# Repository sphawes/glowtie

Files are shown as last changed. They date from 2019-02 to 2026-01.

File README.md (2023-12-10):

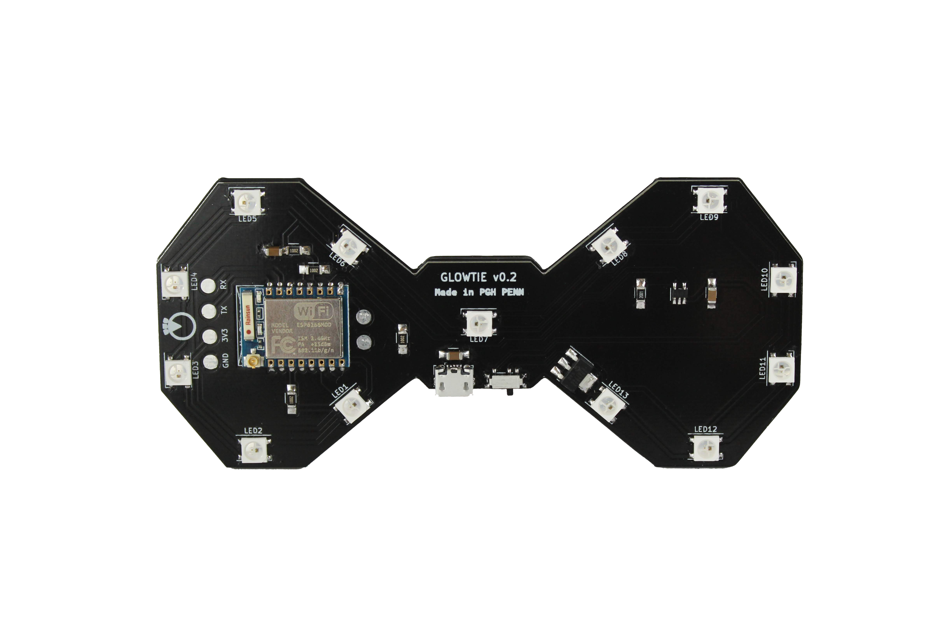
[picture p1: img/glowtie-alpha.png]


## Connecting to your Glowtie

### Android

1. Turn on your Glowtie. There’s a power switch next to the micro usb jack. You should see a gold burst animation; this means the Wifi network has started.
1. On your Android phone, turn off your mobile data. This is so that your phone doesn’t try to reach the actual internet instead of the Glowtie.
1. Open your Wifi settings and look for a network named in the format “AdjectiveClothing”. For example, it could be “FancyPants” or “CoolCoat”. This is the Serial Name of your Glowtie. Connect to the network.
1. You may get a notification that the network you connected to does not have internet access, no worries! Just choose the option to stay connected if you are provided with one.
1. Now open a new tab in Google Chrome and enter the following in the address field: http://192.168.4.1
1. You should see the Glowtie control page! In your Chrome settings, choose to “Add to Home screen” to make it easier to get to in the future.

### iPhone

1. Turn on your Glowtie. You should see a gold burst animation; this means the Wifi network has started.
1. On your iPhone, navigate to Settings -> Cellular and toggle Cellular Data off. This is so that your phone doesn’t try to reach the actual internet instead of the Glowtie.
1. Open your Wifi settings and look for a network named in the format “AdjectiveClothing”. For example, it could be “FancyPants” or “CoolCoat”. This is the Serial Name of your Glowtie. Connect to the network.
1. You may get a notification that the network you connected to does not have internet access, no worries! Just choose the option to stay connected if you are provided with one.
1. Now open a new tab in Safari or Google Chrome and enter the following in the address field: http://192.168.4.1
1. You should see the Glowtie control page! In your Chrome settings, choose to “Add to Home screen” to make it easier to get to in the future. In Safari, tap the share button and select “Add to Home Screen” to do the same.

## Usage

When you load the Glowtie website, you’ll see three sliders. These represent the red, green, and blue values of the lights. When you adjust them, the title background will adjust to show you what color you’re set to.

Once you pick a color, there’s a few options for animations. Tap the button next to the animation you want, then hit the “UPDATE” button. Your Glowtie will change to whatever you selected!



The Glowtie has a built-in memory function, so once you choose a color and animation it’ll remember your choice after you turn it off. This way, you don’t need to connect to it every time you turn it on if you have it set to your favorite pattern.

## Charging

When the Glowtie has low battery, the center LED will turn red. Use a Micro USB cable to recharge your Glowtie. Make sure your Glowtie is turned off, then plug the Micro USB cable into the port next to the power switch. When you plug the other end into a USB port for power, you should see the **top** light on your Glowtie illuminate. When it’s done charging, the **bottom** light will illuminate.

## Cover

Your Glowtie optionally has a diffusion cover. The cover is held on with a friction fit. Laser cut or print `diffusion.dxf` in a white or clear material, 1/16" thick. Print `bumper.stl` in a color of your choice, and super glue the diffusion inside the bumper. The bumper can now be friction fit onto the Glowtie.

## HACK!

The Glowtie is totally open-source. All PCB design files, firmware, and physical parts are hosted on the Github page. There’s a dedicated programming header on the left side so you can add your own animations, or make it do anything you want! Just solder on a few pins and reprogram the ESP8266 over UART.

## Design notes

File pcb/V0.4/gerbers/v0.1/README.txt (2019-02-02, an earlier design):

First version designed for single side, milled on other mill, never sent out

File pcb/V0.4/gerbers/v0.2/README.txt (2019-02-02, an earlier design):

first version sent out to board shop (elecrow) designed for double side, no charging complete or charging indicator lights

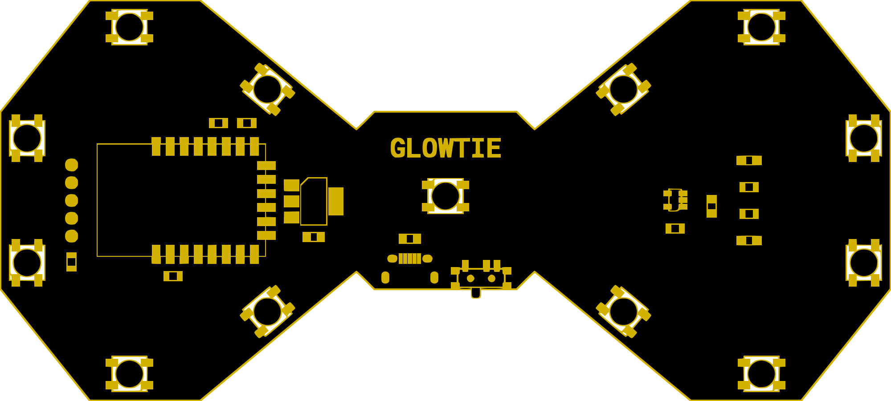
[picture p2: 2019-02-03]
img/glowtieSimplified.png

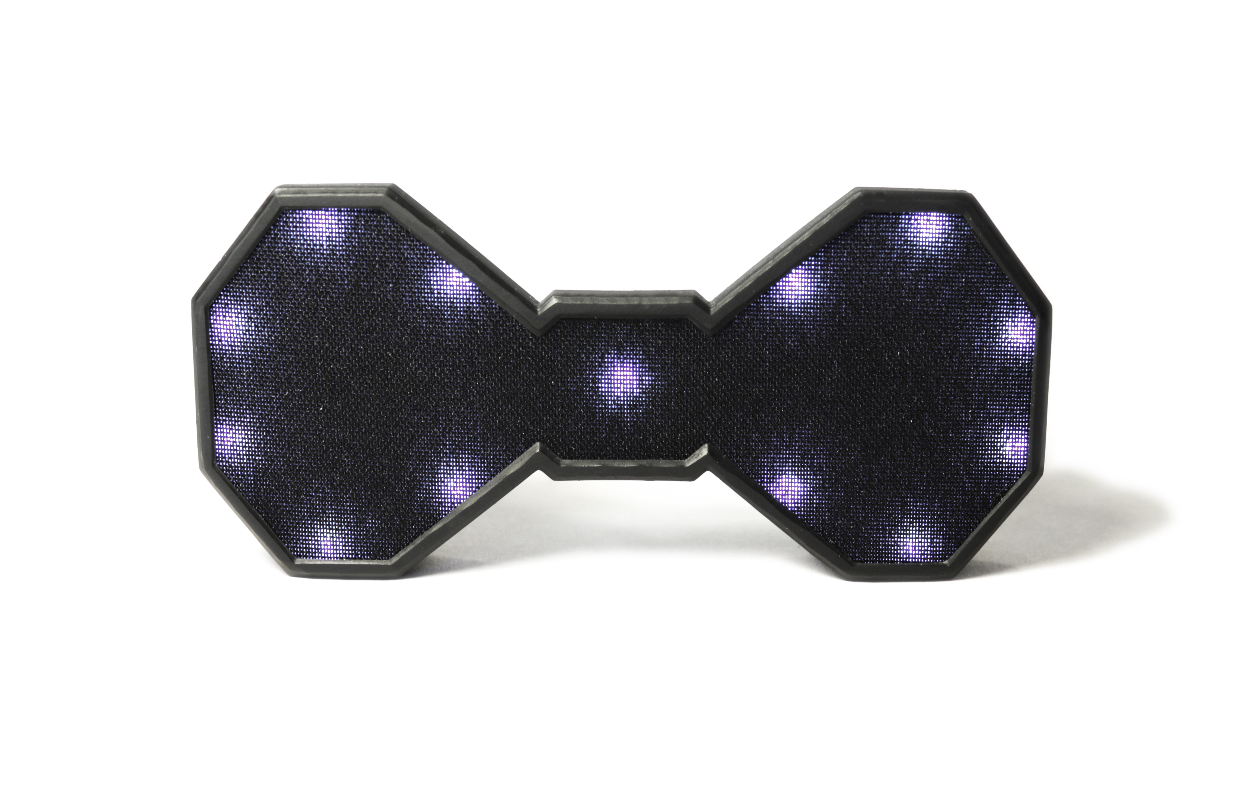
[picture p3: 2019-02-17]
img/glowtieHERO.jpg

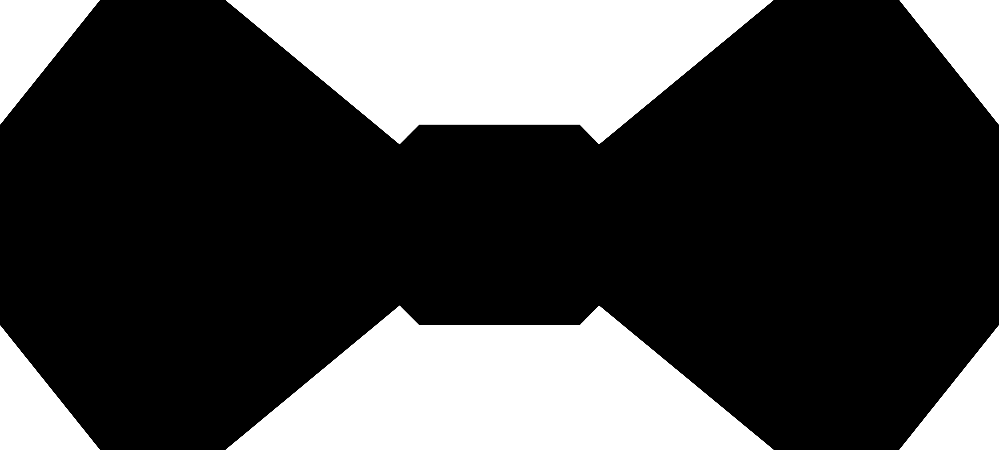
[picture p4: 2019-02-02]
cad/misc/glowtieOutline.jpg

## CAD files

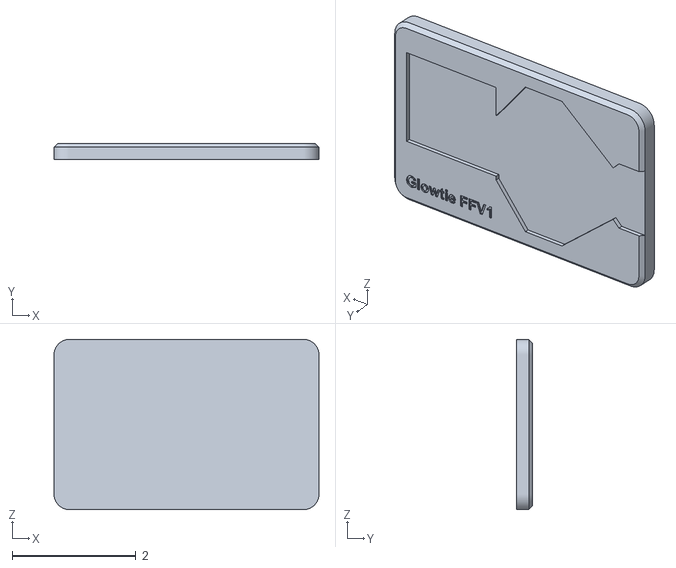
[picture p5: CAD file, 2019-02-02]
cad/misc/firmwareFlasher.stl
4.28 x 0.26 x 2.75

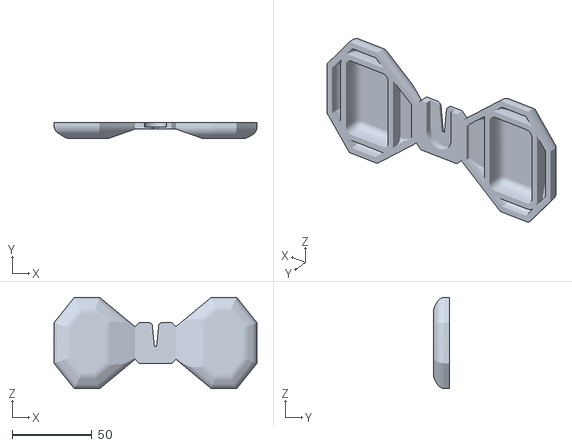
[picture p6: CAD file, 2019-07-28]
cad/v1.0/frame.stl
127.0 x 10.2 x 57.2

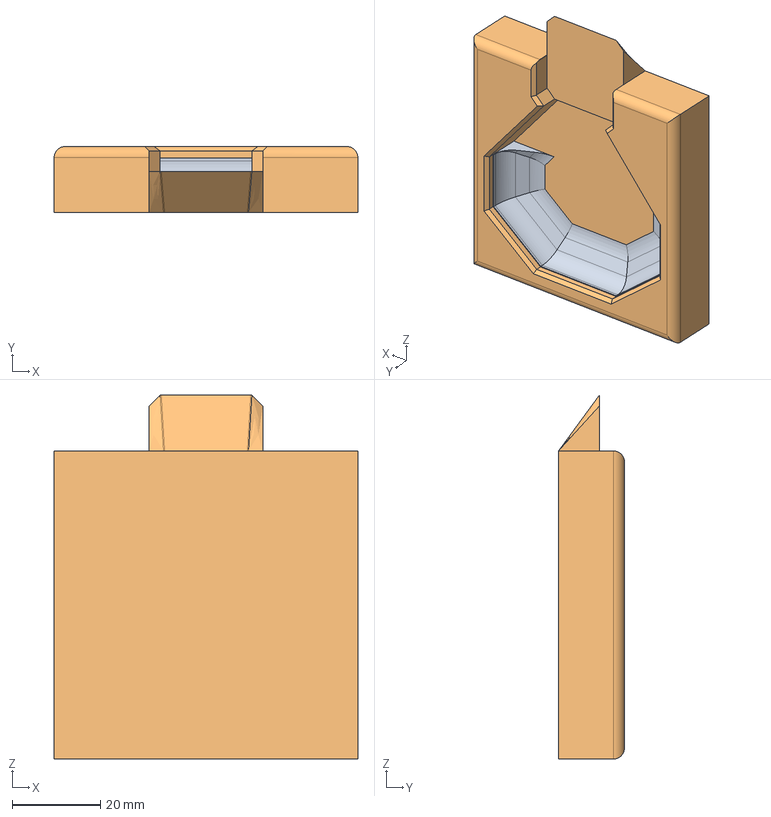
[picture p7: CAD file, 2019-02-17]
programmer/cad/v0.4/cradle.step
69.0 x 15.0 x 82.7 mm

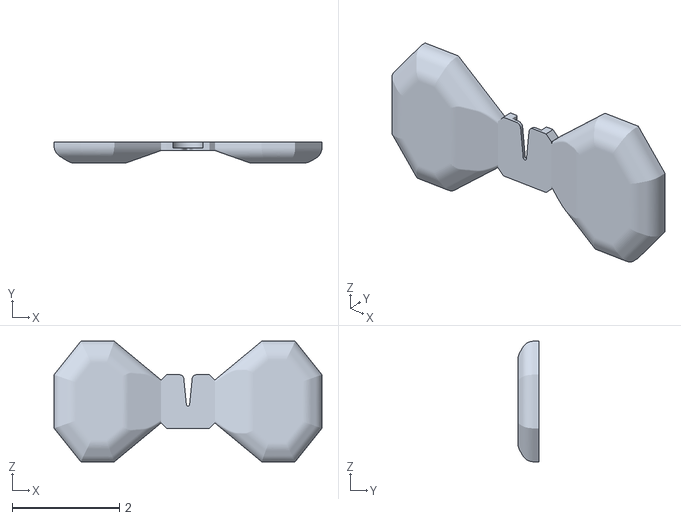
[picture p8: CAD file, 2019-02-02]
cad/misc/frame.stl
5.00 x 0.4 x 2.25

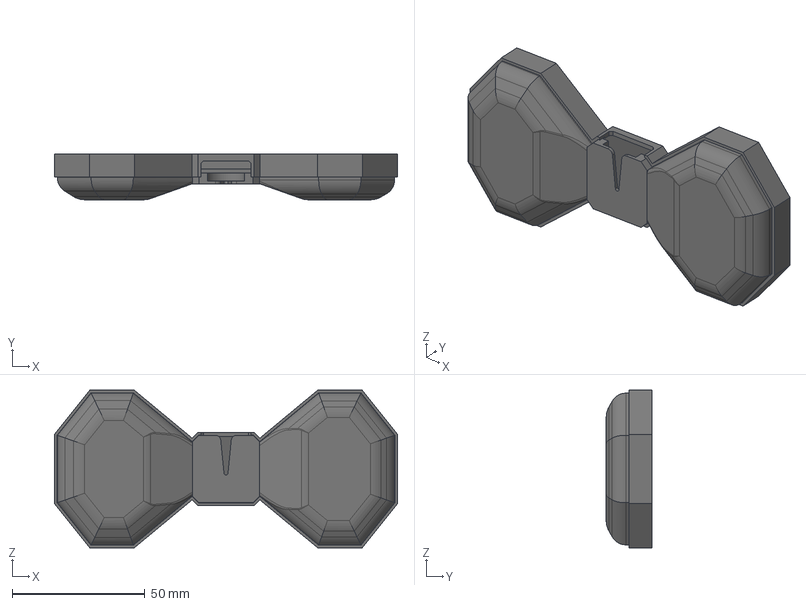
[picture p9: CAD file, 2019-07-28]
cad/v1.0/glowtieV1_0.step
129.2 x 17.2 x 59.4 mm
frame
diffusion
bumper

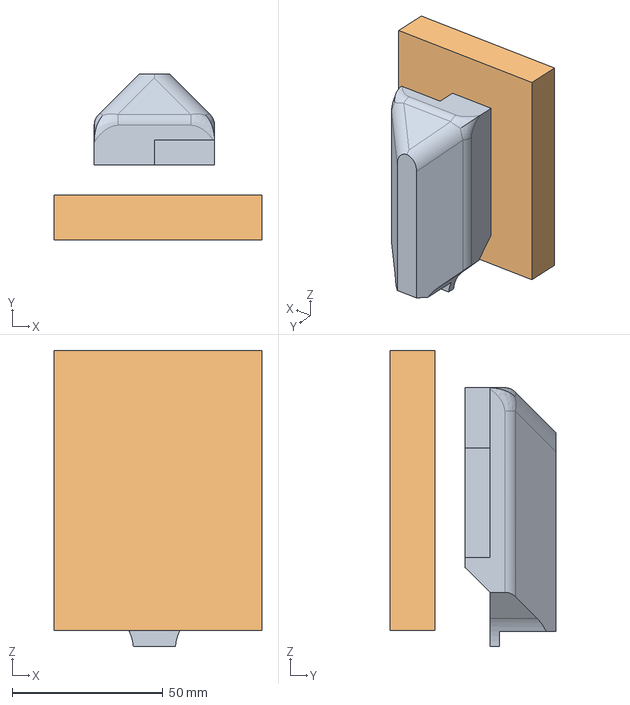
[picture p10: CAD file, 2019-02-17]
programmer/cad/v0.4/head.step
69.0 x 55.2 x 98.3 mm

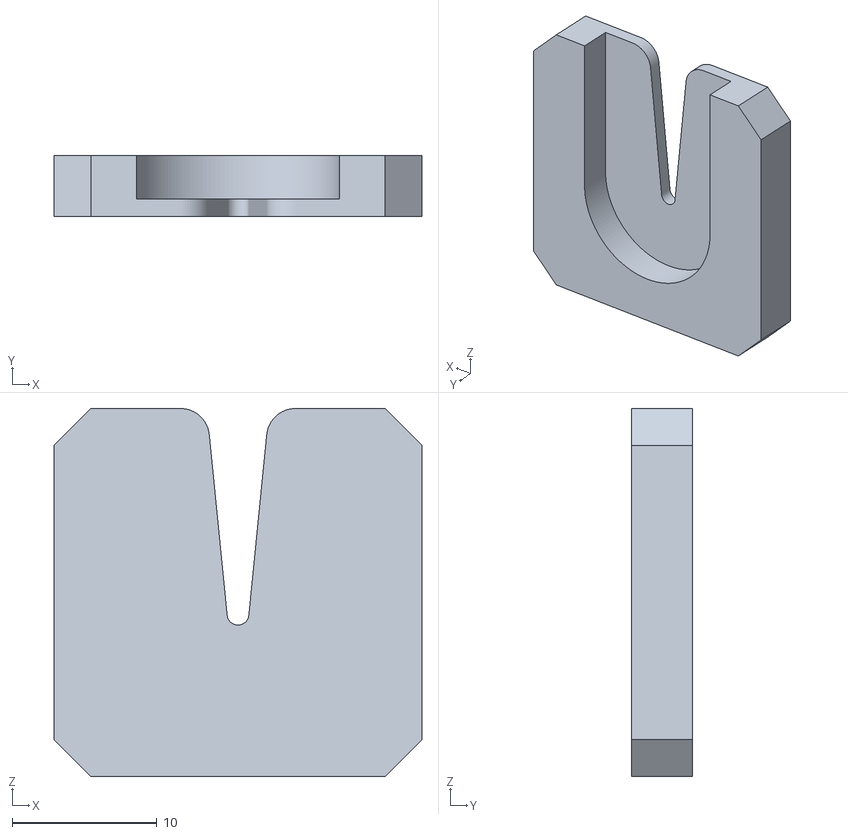
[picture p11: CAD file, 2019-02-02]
cad/misc/buttonSlot.stl
25.4 x 4.20 x 25.4

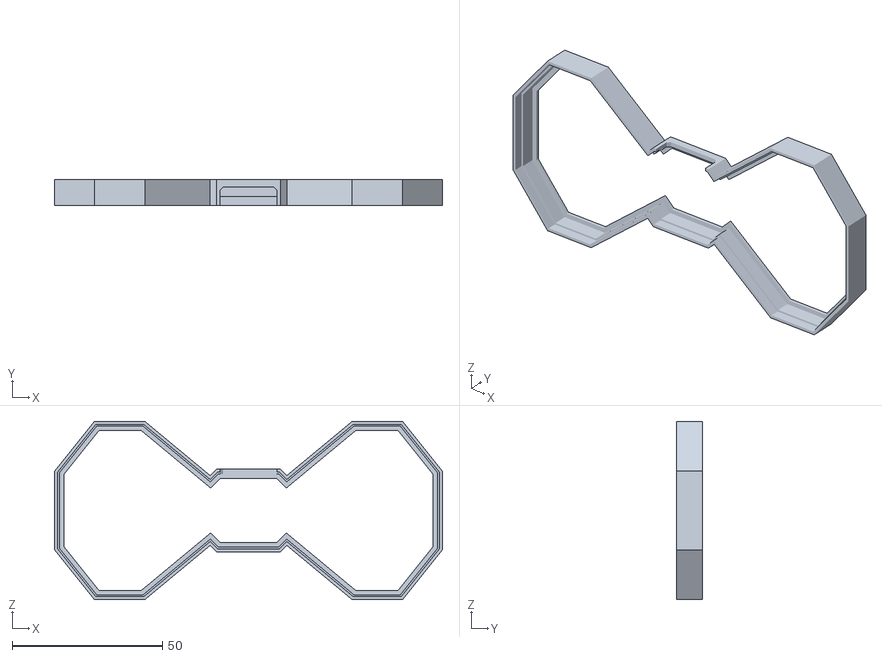
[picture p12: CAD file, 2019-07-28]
cad/v1.0/bumper.stl
129.2 x 8.50 x 59.3

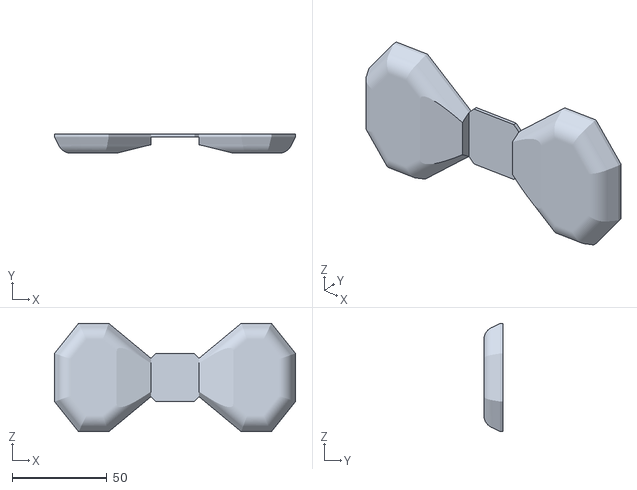
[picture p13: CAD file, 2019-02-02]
cad/misc/backPanel.stl
127.0 x 10.2 x 57.2

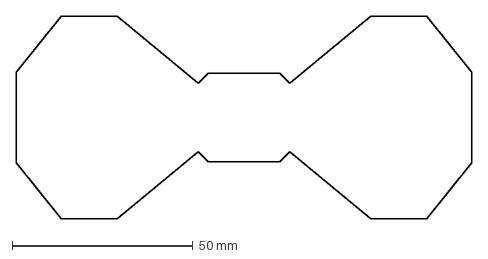
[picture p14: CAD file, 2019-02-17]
cad/v1.0/diffusion.dxf
126.0 x 56.2 mm

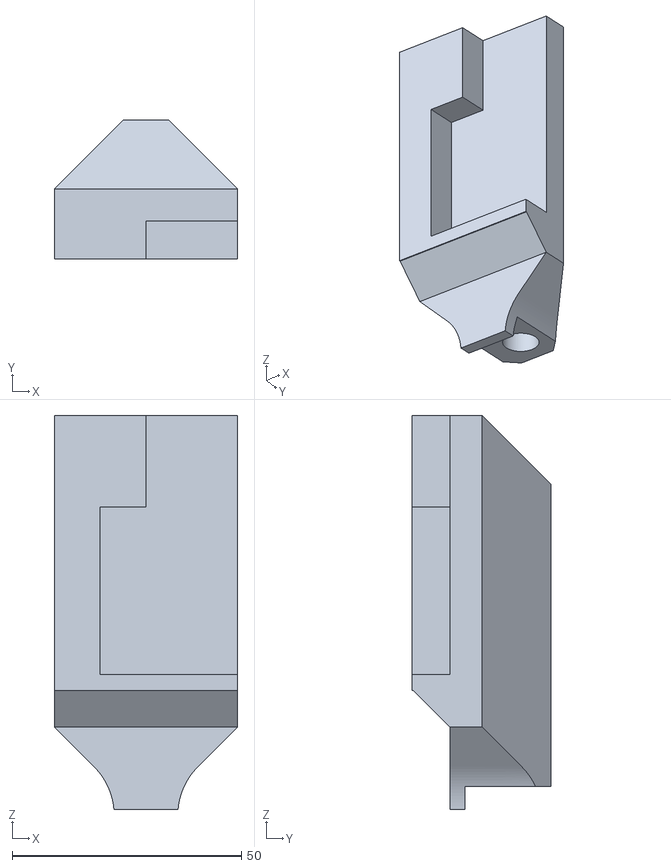
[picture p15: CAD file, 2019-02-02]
cad/misc/programmerHead.stl
40.0 x 30.2 x 86.0

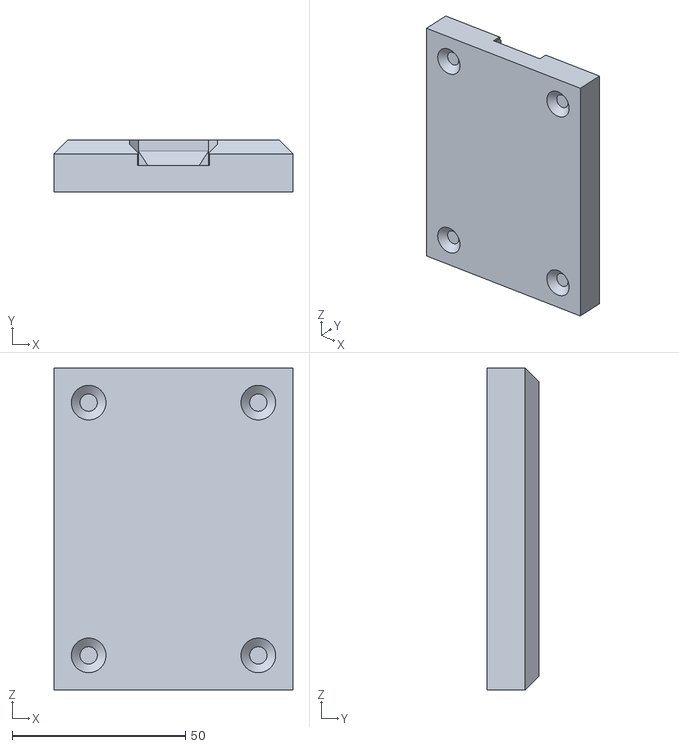
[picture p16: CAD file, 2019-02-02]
cad/misc/programmerBase.stl
69.0 x 15.0 x 93.0

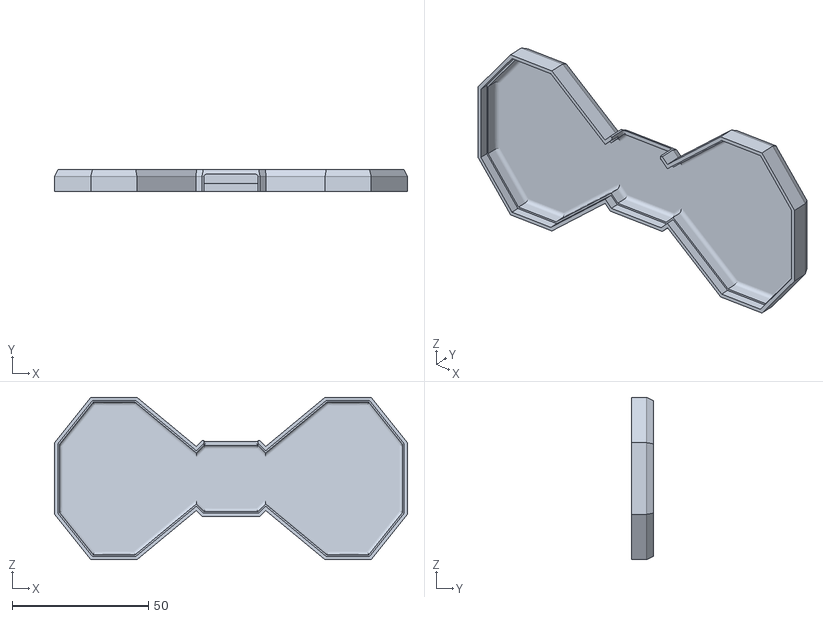
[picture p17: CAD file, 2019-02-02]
cad/misc/frontPanel.stl
129.4 x 8.15 x 59.5

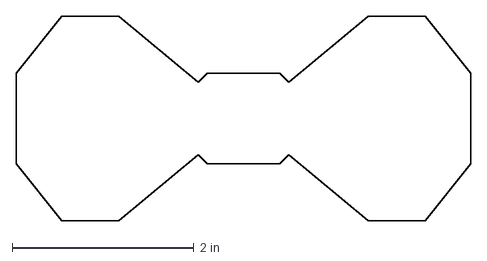
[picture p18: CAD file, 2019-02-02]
cad/misc/glowtieOutline.dxf
5.00 x 2.25 in

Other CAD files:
cad/v0.4/bumper.step
cad/v0.4/frame.step
cad/v0.4/bumper.stl
cad/v0.4/frame.stl

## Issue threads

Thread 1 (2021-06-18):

Enable Issues for the index PnP machine?

hoijui, 2021-06-18:
Could you please enable "issues" for that repo?
https://github.com/sphawes/index

(they are not enabled because you forked it)

I wanted to report there, that the BoM (which was hosted on google docs) is missing/deleted:
https://docs.google.com/spreadsheets/d/1N7jMZ2upi8-9_jjJnl2xC9bYtZuE1wX5Qzoa-qs21eY/edit#gid=476120456

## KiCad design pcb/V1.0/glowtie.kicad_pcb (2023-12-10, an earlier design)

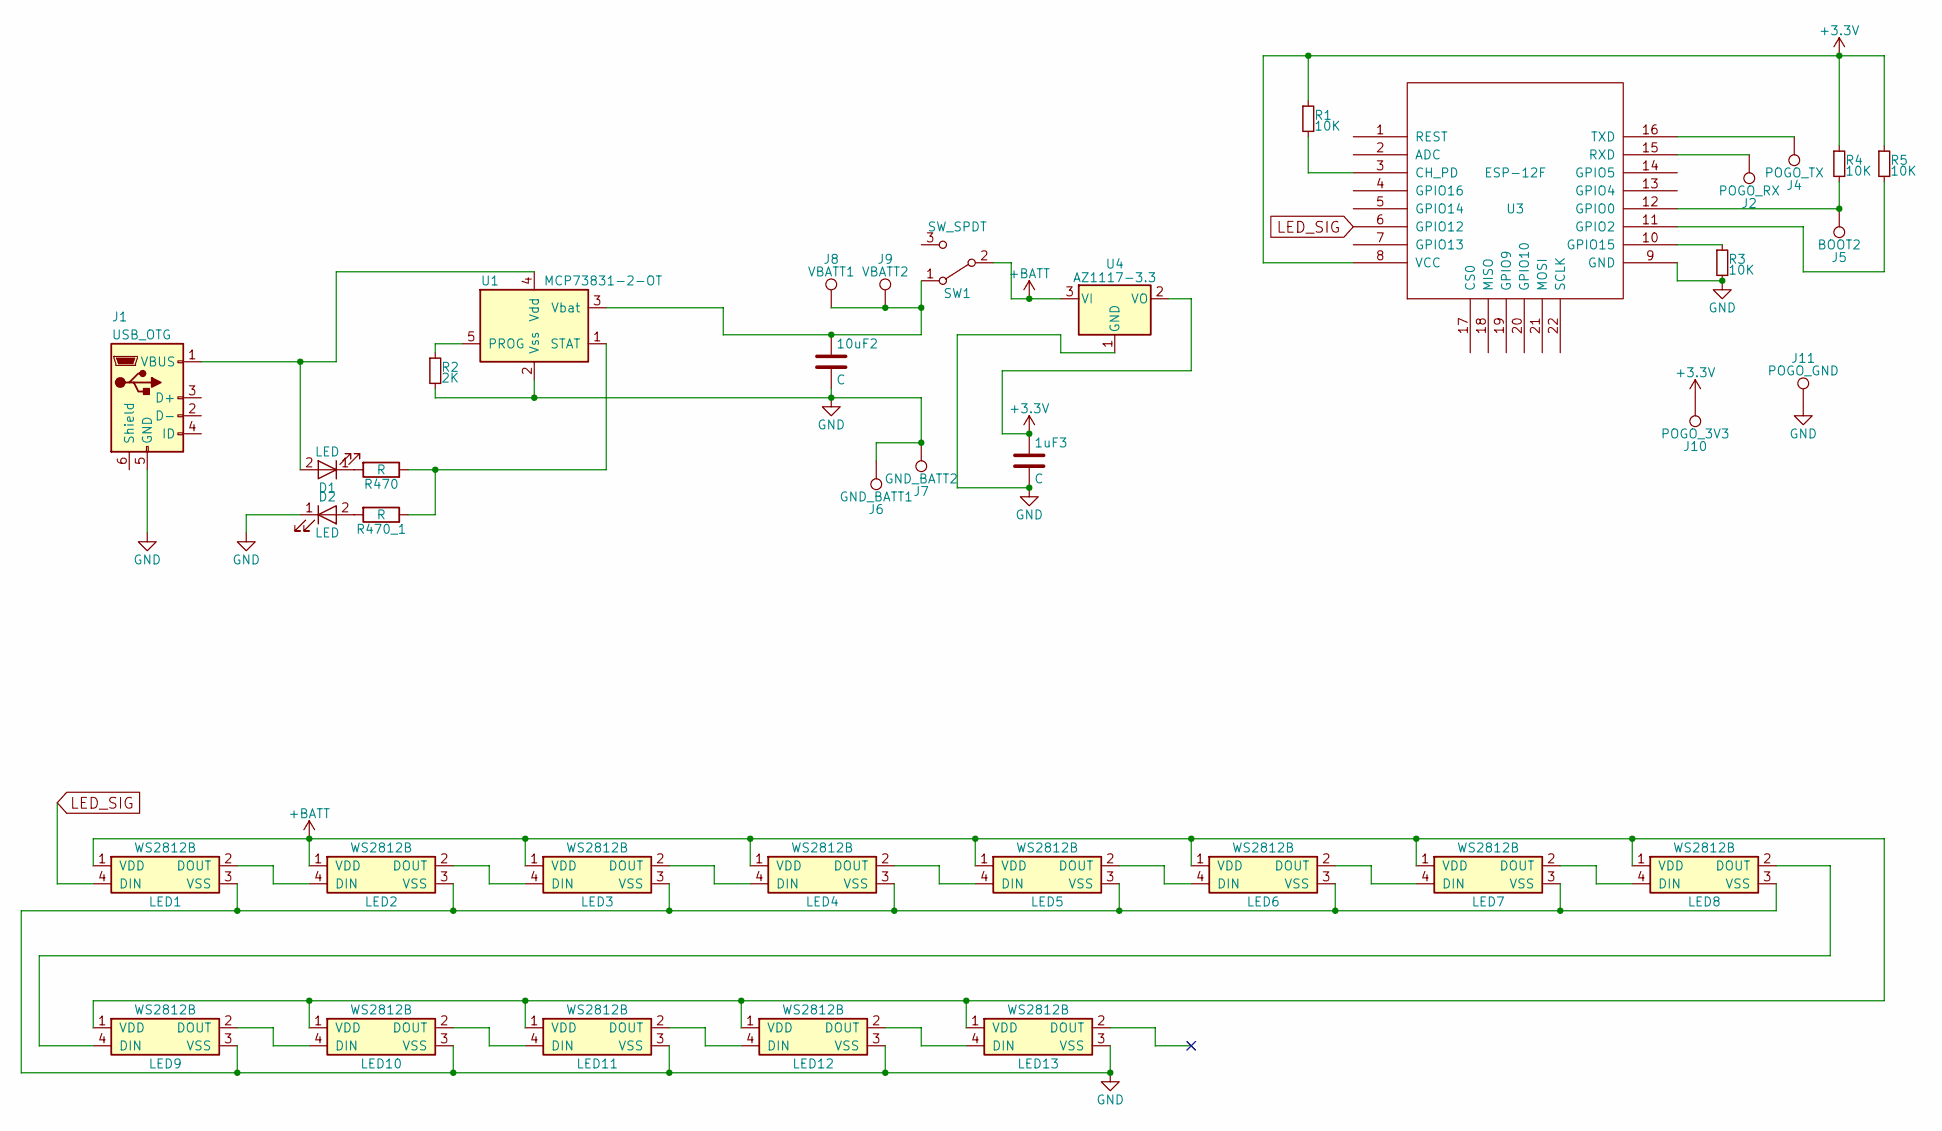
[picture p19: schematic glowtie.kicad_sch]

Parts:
1uF3, 10uF2: C; C_0805
D1, D2: LED; LED_0805
J1: USB_OTG; USB_Micro-B
J2: POGO_RX; TestPoint_Pad_D1.5mm
J4: POGO_TX; TestPoint_Pad_D1.5mm
J5: BOOT2; TestPoint_Pad_D1.5mm
J6: GND_BATT1; Measurement_Point_Square-SMD-Pad_Big
J7: GND_BATT2; Measurement_Point_Square-SMD-Pad_Big
J8: VBATT1; Measurement_Point_Round-SMD-Pad_Big
J9: VBATT2; Measurement_Point_Round-SMD-Pad_Big
J10: POGO_3V3; TestPoint_Pad_D1.5mm
J11: POGO_GND; TestPoint_Pad_D1.5mm
LED1, LED2, LED3, LED4, LED5, LED6, LED7, LED8, LED9, LED10, LED11, LED12, LED13: WS2812B; LED_WS2812B-PLCC4
R1, R3, R4, R5: 10K; R_0805
R2: 2K; R_0805
R470, R470_1: R; R_0805
SW1: SW_SPDT; SW_SPDT_PCM12
U1: MCP73831-2-OT; SOT-23-5
U3: ESP-12F; ESP-12E_SMD
U4: AZ1117-3.3; SOT-223-3_TabPin2

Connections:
+3V3: 1uF3.1, J10.1, R1.1, R4.1, R5.1, U3.8 (VCC), U4.2 (VO)
+BATT: LED1.1 (VDD), LED2.1 (VDD), LED3.1 (VDD), LED4.1 (VDD), LED5.1 (VDD), LED6.1 (VDD), LED7.1 (VDD), LED8.1 (VDD), LED9.1 (VDD), LED10.1 (VDD), LED11.1 (VDD), LED12.1 (VDD), LED13.1 (VDD), SW1.2 (B), U4.3 (VI)
GND: 1uF3.2, 10uF2.2, D2.1 (K), J1.5 (GND), J6.1, J7.1, J11.1, LED1.3 (VSS), LED2.3 (VSS), LED3.3 (VSS), LED4.3 (VSS), LED5.3 (VSS), LED6.3 (VSS), LED7.3 (VSS), LED8.3 (VSS), LED9.3 (VSS), LED10.3 (VSS), LED11.3 (VSS), LED12.3 (VSS), LED13.3 (VSS), R2.2, R3.2, U1.2 (Vss), U3.9 (GND), U4.1 (GND)
LED_SIG: LED1.4 (DIN), U3.6 (GPIO12)
unnamed: D1.2 (A), J1.1 (VBUS), U1.4 (Vdd)
unnamed: D1.1 (K), R470.2
unnamed: D2.2 (A), R470_1.2
unnamed: LED1.2 (DOUT), LED2.4 (DIN)
unnamed: LED2.2 (DOUT), LED3.4 (DIN)
unnamed: LED3.2 (DOUT), LED4.4 (DIN)
unnamed: LED4.2 (DOUT), LED5.4 (DIN)
unnamed: LED5.2 (DOUT), LED6.4 (DIN)
unnamed: LED6.2 (DOUT), LED7.4 (DIN)
unnamed: LED7.2 (DOUT), LED8.4 (DIN)
unnamed: LED8.2 (DOUT), LED9.4 (DIN)
unnamed: LED9.2 (DOUT), LED10.4 (DIN)
unnamed: LED10.2 (DOUT), LED11.4 (DIN)
unnamed: LED11.2 (DOUT), LED12.4 (DIN)
unnamed: LED12.2 (DOUT), LED13.4 (DIN)
unnamed: 10uF2.1, J8.1, J9.1, SW1.1 (A), U1.3 (Vbat)
unnamed: R2.1, U1.5 (PROG)
unnamed: R470.1, R470_1.1, U1.1 (STAT)
unnamed: R1.2, U3.3 (CH_PD)
unnamed: J5.1, R4.2, U3.12 (GPIO0)
unnamed: R5.2, U3.11 (GPIO2)
unnamed: R3.1, U3.10 (GPIO15)
unnamed: J2.1, U3.15 (RXD)
unnamed: J4.1, U3.16 (TXD)

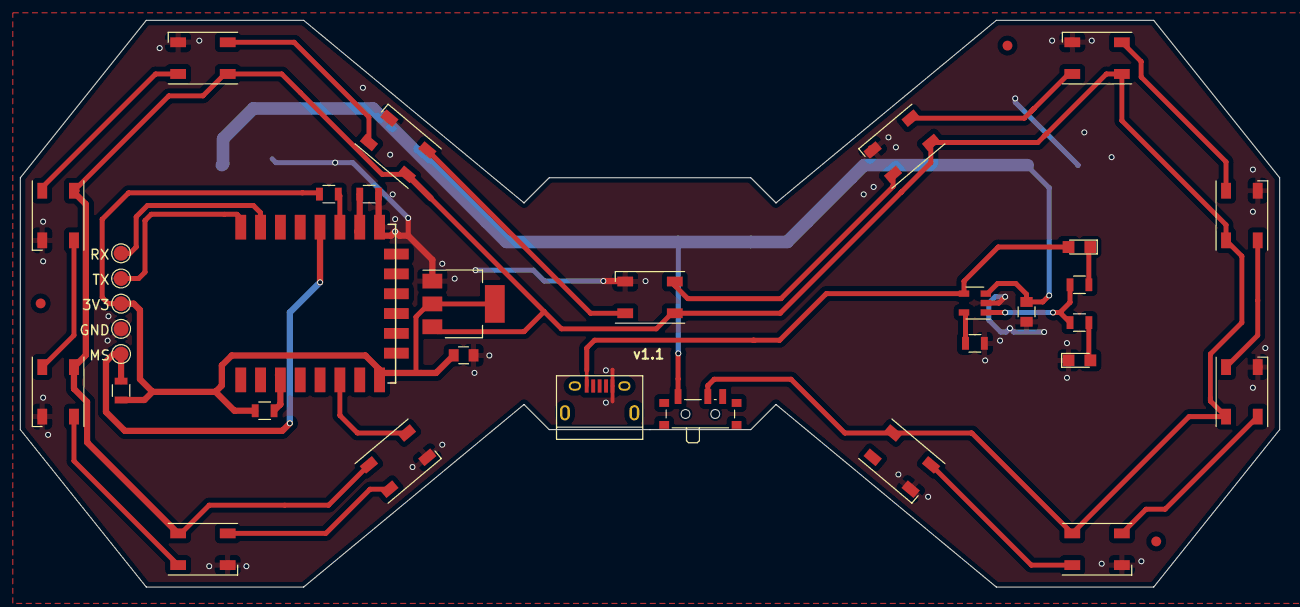
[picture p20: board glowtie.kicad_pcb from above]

Board: 2 copper layers, 127.0 x 57.1 mm, 38 parts (0 on the bottom side), 28 nets.

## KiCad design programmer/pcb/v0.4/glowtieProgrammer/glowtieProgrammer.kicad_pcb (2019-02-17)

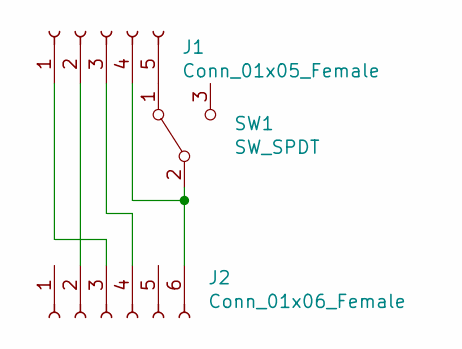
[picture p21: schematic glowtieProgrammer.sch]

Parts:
J1: Conn_01x05_Female; Pin_Header_Straight_1x05_Pitch2.54mm
J2: Conn_01x06_Female; Pin_Header_Straight_1x06_Pitch2.54mm
SW1: SW_SPDT; SW_SPDT_PCM12

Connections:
unnamed: J1.1, J2.3
unnamed: J1.2, J2.2
unnamed: J1.3, J2.4
unnamed: J1.4, J2.6, SW1.2 (B)
unnamed: J1.5, SW1.1 (A)

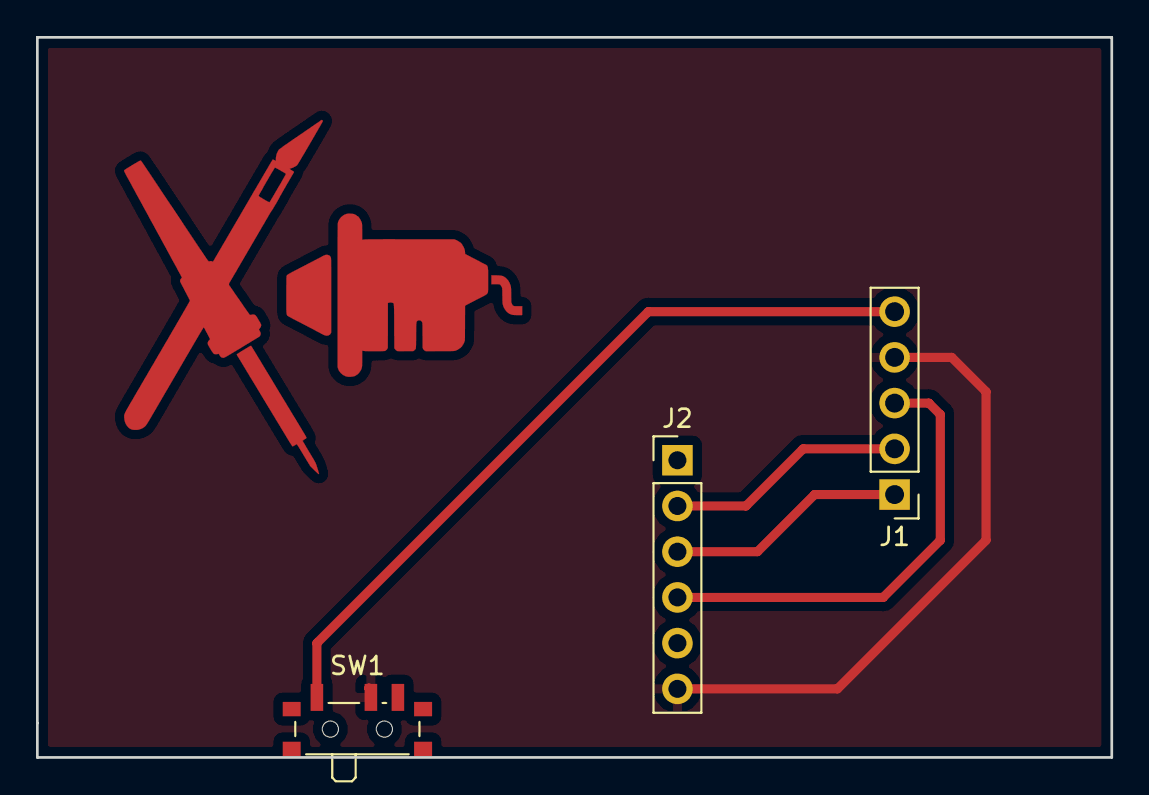
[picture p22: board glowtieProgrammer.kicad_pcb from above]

Board: 2 copper layers, 59.7 x 40.0 mm, 3 parts (0 on the bottom side), 5 nets.

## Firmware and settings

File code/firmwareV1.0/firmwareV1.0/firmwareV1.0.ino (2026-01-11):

//Glowtie Firmware v1.0
//Stephen Hawes 2019
//TOOLS:
//Stringify HTML file:
//http://davidjwatts.com/youtube/esp8266/esp-convertHTM.html#
//Reference for sending data between site and server
//https://bitbucket.org/Remnis/neopixelwebserver/src/0ae6ce3b2122?at=master
//https://github.com/jasoncoon/esp8266-fastled-webserver/blob/master/data/index.htm

#include <Adafruit_NeoPixel.h>
#include <ESP8266WiFi.h>
#include <WiFiClient.h>
#include <ESP8266WebServer.h>
#include <EEPROM.h>

#define PIN            12
#define NUMPIXELS      13

#define SN "CarefulBelt"

Adafruit_NeoPixel pixels = Adafruit_NeoPixel(NUMPIXELS, PIN, NEO_GRB + NEO_KHZ800);

ADC_MODE(ADC_VCC);

const char *ssid = SN;
const char *password = "pleaseletmein";

ESP8266WebServer server(80);

int const battCacheSize = 30;
int battCachePosition = 0;
int battCache[battCacheSize] = {3300, 3300, 3300, 3300, 3300, 3300, 3300, 3300, 3300, 3300, 3300, 3300, 3300, 3300, 3300, 3300, 3300, 3300, 3300, 3300, 3300, 3300, 3300, 3300, 3300, 3300, 3300, 3300, 3300, 3300};
int summedCache = 99000;
float avgBatt = 3300;
int newBatt = 0;

int delayVal = 8;
int btMode = 0;
int rVal = 0;
int gVal = 0;
int bVal = 0;
int brightness = 30;
int checkBattTimer = 0;
int prevMode = 0;

int ba = 0;
int bb = 0;
int bc = 0;
int bd = 0;
int bi = 0;

int pa = 0;
int pi = 0;

int ii = 0;

unsigned long prevMillis = millis();

void setup() {
  Serial.begin(115200);

  pixels.begin();

  //storing 4 eeprom values. the 0th is the saved mode, then the 1-3th are r, g, and b values, respectively. 4 bytes per int with 4 ints is 16 bytes:
  EEPROM.begin(512);

  btMode = EEPROM.read(0);
  rVal = EEPROM.read(4);
  gVal = EEPROM.read(8);
  bVal = EEPROM.read(12);

  //CHECKING BATTERY

  newBatt = ESP.getVcc();
  if (newBatt <= 3100) {
    btMode = 1;
    Serial.println("Battery low, going into low battery mode.");
  }

  //Animation
  for (int j = 0; j < 300; j++) {
    burst(50, 20, 0);
    delay(10);
  }

  //WIFI JAZZ
  Serial.print("Creating Glowtie netowork...");
  if (WiFi.softAP(ssid)) {
    Serial.println("Successfully started access point.");
  }
  else {
    Serial.println("Could not start access point.");
  }

  IPAddress myIP = WiFi.softAPIP();
  Serial.print("IP address: ");
  Serial.println(myIP);

  server.on("/", handleRoot);
  server.begin();

  //END WIFI STUFF

  checkBattTimer = millis();

}



void loop() {
  //yield();
  server.handleClient();
  //Checking battery value

  if (millis() >= checkBattTimer + 5000) {
    newBatt = ESP.getVcc();
    Serial.println(newBatt);
    if (newBatt <= 3100) {
      btMode = 1;
    }
    checkBattTimer = millis();
  }


  //OFF MODE
  if (btMode == 0) {
    if (prevMode != 0) {
      off();
      prevMode = 0;
    }
  }

  //LOW BATTERY MODE
  else if (btMode == 1) {
    if (prevMode != 1) {
      lowBatt();
      prevMode = 1;
    }
  }

  //SOLID COLOR MODE
  else if (btMode == 2) {
    if (prevMode != 2) {
      solid();
      prevMode = 2;
    }
  }

  //INFINITY MODE
  else if (btMode == 3) {
    if (prevMode != 3) {
      prevMillis = millis() - 71;
      prevMode = 3;
      ii = 0;
    }
    if (millis() > prevMillis + 70) {
      prevMillis = millis();
      infin(rVal, gVal, bVal);
    }
  }

  //PULSE MODE
  else if (btMode == 4) {
    if (prevMode != 4) {
      pi = 0;
      prevMode = 4;
    }
    if (millis() > prevMillis + 7) {
      prevMillis = millis();
      pulse(rVal, gVal, bVal);
    }
  }

  //BURST MODE
  else if (btMode == 5) {
    if (prevMode != 5) {
      bi = 0;
      prevMode = 5;
    }
    if (millis() > prevMillis + 10) {
      //Burst mode
      prevMillis = millis();
      burst(rVal, gVal, bVal);
    }
  }
}

void handleRoot() {
  //off();

  if (server.args() > 0) {
    int r = server.arg("red").toInt();
    int g = server.arg("green").toInt();
    int b = server.arg("blue").toInt();
    String btModeS = server.arg("mode");
    btMode = btModeS.toInt();

    int red = r / 3;
    int green = g / 3;
    int blue = b / 3;

    rVal = red;
    gVal = green;
    bVal = blue;

    EEPROM.write(0, btMode);
    EEPROM.write(4, rVal);
    EEPROM.write(8, gVal);
    EEPROM.write(12, bVal);
    EEPROM.commit();
  }

  //String html ="<!DOCTYPE html> <html> <head> <title>Glowtie</title> <style> body { background-color: #000000; font-family: \"Helvetica\"; color: #ffffff; } .slider{ width:90%; } #colorUpdate{ background-color: black; width:200px; height:40px; margin:auto; text-align: center; padding:20px; border-radius: 10px; } </style> <meta name=\"viewport\" content=\"width=device-width, height=device-height, initial-scale=1.0, user-scalable=0, minimum-scale=1.0, maximum-scale=1.0\" /> <script> console.log(\"Inline JS running.\"); function updateColor(){ var red = document.forms['settings'].red.value; var green = document.forms['settings'].green.value; var blue = document.forms['settings'].blue.value; var rgb = blue | (green << 8) | (red << 16); var color = \"#\" + (0x1000000 + rgb).toString(16).slice(1); document.getElementById(\"colorUpdate\").style.backgroundColor = color; } </script> </head> <body> <h1 id=\"colorUpdate\">Glowtie</h1> <form action=\"\" name=\"settings\" id=\"settings\" method=\"post\"> <!--Color: <input class=\"jscolor\" value=\"ffffff\" name=\"color\">--> Red:<br /> <input type=\"range\" class=\"slider\" min=\"0\" max=\"255\" value=\"127\" name=\"red\" onchange=\"updateColor()\"><br /> Green<br /> <input type=\"range\" class=\"slider\" min=\"0\" max=\"255\" value=\"127\" name=\"green\" onchange=\"updateColor()\"><br /> Blue<br /> <input type=\"range\" class=\"slider\" min=\"0\" max=\"255\" value=\"127\" name=\"blue\" onchange=\"updateColor()\"><br /> <input type=\"radio\" name=\"mode\" value=\"0\" checked> Off<br /> <input type=\"radio\" name=\"mode\" value=\"2\"> Solid<br /> <input type=\"radio\" name=\"mode\" value=\"3\"> Infinity<br /> <input type=\"radio\" name=\"mode\" value=\"4\"> Breathe<br /> <input type=\"radio\" name=\"mode\" value=\"5\"> Burst<br /><br /> <button onclick=\"document.forms['settings'].submit()\" type=\"button\">Send to Glowtie!</button> </form> </body> </html>";
  String html = "<!DOCTYPE html> <html> <head> <title>Glowtie</title> <style> body { background-color: #000000; font-family: \"Helvetica\"; color: #ffffff; } .slider { -webkit-appearance: none; /* Override default CSS styles */ appearance: none; width: 100%; /* Full-width */ margin:auto; margin-bottom:40px; margin-top:10px; height: 25px; /* Specified height */ background:black; /* Grey background */ outline: none; /* Remove outline */ opacity: 0.7; /* Set transparency (for mouse-over effects on hover) */ -webkit-transition: .2s; /* 0.2 seconds transition on hover */ transition: opacity .2s; border:3px solid white; } .slider::-webkit-slider-thumb { -webkit-appearance: none; /* Override default look */ appearance: none; width: 50px; /* Set a specific slider handle width */ height: 50px; /* Slider handle height */ background: white; /* Green background */ cursor: pointer; /* Cursor on hover */ border-radius: 5px; border: 1px solid black; } #sliderCont { width:70%; margin:auto; } #colorUpdate{ background-color: black; width:200px; height:40px; margin:auto; text-align: center; padding:20px; border-radius: 10px; font-family:'Courier New', Courier, monospace } .container { display: block; position: relative; padding-left: 80px; padding-top:5px; margin-bottom: 30px; cursor: pointer; font-size: 22px; font-family: \"Courier New\"; font-weight: bold; color:white; -webkit-user-select: none; -moz-user-select: none; -ms-user-select: none; user-select: none; } /* Hide the browser's default radio button */ .container input { position: absolute; opacity: 0; cursor: pointer; } /* Create a custom radio button */ .checkmark { position: absolute; top: 0; left: 0; height: 40px; width: 70px; background-color: white; border-radius: 10px; } /* On mouse-over, add a grey background color */ .container:hover input ~ .checkmark { background-color: #ccc; } /* When the radio button is checked, add a blue background */ .container input:checked ~ .checkmark { background-color: gold; } /* Create the indicator (the dot/circle - hidden when not checked) */ .checkmark:after { content: \"\"; position: absolute; display: none; } /* Show the indicator (dot/circle) when checked */ .container input:checked ~ .checkmark:after { display: block; } /* Style the indicator (dot/circle) */ .container .checkmark:after { top: 15px; left: 15px; width: 40px; height: 10px; border-radius: 3px; background: black; } </style> <meta name=\"viewport\" content=\"width=device-width, height=device-height, initial-scale=1.0, user-scalable=0, minimum-scale=1.0, maximum-scale=1.0\" /> <script> console.log(\"Inline JS running.\"); function updateColor(){ var red = document.forms['settings'].red.value; var green = document.forms['settings'].green.value; var blue = document.forms['settings'].blue.value; var rgb = blue | (green << 8) | (red << 16); var color = \"#\" + (0x1000000 + rgb).toString(16).slice(1); document.getElementById(\"colorUpdate\").style.backgroundColor = color; } </script> </head> <body> <h1 id=\"colorUpdate\">Glowtie</h1> <form action=\"\" name=\"settings\" id=\"settings\" method=\"post\"> <!--Color: <input class=\"jscolor\" value=\"ffffff\" name=\"color\">--> <div id=\"sliderCont\"> RED<br /> <input type=\"range\" class=\"slider\" min=\"0\" max=\"255\" value=\"127\" name=\"red\" onchange=\"updateColor()\"><br /> GREEN<br /> <input type=\"range\" class=\"slider\" min=\"0\" max=\"255\" value=\"127\" name=\"green\" onchange=\"updateColor()\"><br /> BLUE<br /> <input type=\"range\" class=\"slider\" min=\"0\" max=\"255\" value=\"127\" name=\"blue\" onchange=\"updateColor()\"><br /> </div> <br /> <div style=\"width:200px;margin:auto;\"> <!-- <input class=\"radio\" type=\"radio\" name=\"mode\" value=\"0\" checked> Off<br /> <input class=\"radio\" type=\"radio\" name=\"mode\" value=\"2\"> Solid<br /> <input class=\"radio\" type=\"radio\" name=\"mode\" value=\"3\"> Infinity<br /> <input class=\"radio\" type=\"radio\" name=\"mode\" value=\"4\"> Breathe<br /> <input class=\"radio\" type=\"radio\" name=\"mode\" value=\"5\"> Burst<br /><br />--> <label class=\"container\">Off <input type=\"radio\" checked=\"checked\" name=\"mode\" value=\"0\"> <span class=\"checkmark\"></span> </label> <label class=\"container\">Solid <input type=\"radio\" name=\"mode\" value=\"2\"> <span class=\"checkmark\"></span> </label> <label class=\"container\">Infinity <input type=\"radio\" name=\"mode\" value=\"3\"> <span class=\"checkmark\"></span> </label> <label class=\"container\">Breathe <input type=\"radio\" name=\"mode\" value=\"4\"> <span class=\"checkmark\"></span> </label> <label class=\"container\">Burst <input type=\"radio\" name=\"mode\" value=\"5\"> <span class=\"checkmark\"></span> </label> <button style=\"width:150px;height:50px;background-color:gold;color:black;position:relative;margin-left:25px;margin-top:20px;font-family: 'Courier New', Courier, monospace;font-size:20px;border:0px;border-radius:10px;\" onclick=\"document.forms['settings'].submit()\" type=\"button\">UPDATE</button> </div> </form> </body> </html>";


  server.send(200, "text/html", html);


}

void updateAvgBatt() {
  newBatt = ESP.getVcc();
  summedCache = summedCache - battCache[battCachePosition];
  summedCache = summedCache + newBatt;
  battCache[battCachePosition] = newBatt;

  if (battCachePosition == (battCacheSize - 1)) {
    battCachePosition = 0;
  }
  else {
    battCachePosition++;
  }
  avgBatt = summedCache / battCacheSize;

}

void off() {
  pixels.setPixelColor(0, pixels.Color(0, 0, 0));
  pixels.setPixelColor(1, pixels.Color(0, 0, 0));
  pixels.setPixelColor(2, pixels.Color(0, 0, 0));
  pixels.setPixelColor(3, pixels.Color(0, 0, 0));
  pixels.setPixelColor(4, pixels.Color(0, 0, 0));
  pixels.setPixelColor(5, pixels.Color(0, 0, 0));
  pixels.setPixelColor(6, pixels.Color(0, 0, 0));
  pixels.setPixelColor(7, pixels.Color(0, 0, 0));
  pixels.setPixelColor(8, pixels.Color(0, 0, 0));
  pixels.setPixelColor(9, pixels.Color(0, 0, 0));
  pixels.setPixelColor(10, pixels.Color(0, 0, 0));
  pixels.setPixelColor(11, pixels.Color(0, 0, 0));
  pixels.setPixelColor(12, pixels.Color(0, 0, 0));
  pixels.show();
}

void lowBatt() {
  pixels.setPixelColor(0, pixels.Color(0, 0, 0));
  pixels.setPixelColor(1, pixels.Color(0, 0, 0));
  pixels.setPixelColor(2, pixels.Color(0, 0, 0));
  pixels.setPixelColor(3, pixels.Color(0, 0, 0));
  pixels.setPixelColor(4, pixels.Color(0, 0, 0));
  pixels.setPixelColor(5, pixels.Color(0, 0, 0));
  pixels.setPixelColor(6, pixels.Color(50, 0, 0));
  pixels.setPixelColor(7, pixels.Color(0, 0, 0));
  pixels.setPixelColor(8, pixels.Color(0, 0, 0));
  pixels.setPixelColor(9, pixels.Color(0, 0, 0));
  pixels.setPixelColor(10, pixels.Color(0, 0, 0));
  pixels.setPixelColor(11, pixels.Color(0, 0, 0));
  pixels.setPixelColor(12, pixels.Color(0, 0, 0));

  pixels.show();
}

void solid() {
  pixels.setPixelColor(0, pixels.Color(rVal, gVal, bVal));
  pixels.setPixelColor(1, pixels.Color(rVal, gVal, bVal));
  pixels.setPixelColor(2, pixels.Color(rVal, gVal, bVal));
  pixels.setPixelColor(3, pixels.Color(rVal, gVal, bVal));
  pixels.setPixelColor(4, pixels.Color(rVal, gVal, bVal));
  pixels.setPixelColor(5, pixels.Color(rVal, gVal, bVal));
  pixels.setPixelColor(6, pixels.Color(rVal, gVal, bVal));
  pixels.setPixelColor(7, pixels.Color(rVal, gVal, bVal));
  pixels.setPixelColor(8, pixels.Color(rVal, gVal, bVal));
  pixels.setPixelColor(9, pixels.Color(rVal, gVal, bVal));
  pixels.setPixelColor(10, pixels.Color(rVal, gVal, bVal));
  pixels.setPixelColor(11, pixels.Color(rVal, gVal, bVal));
  pixels.setPixelColor(12, pixels.Color(rVal, gVal, bVal));

  pixels.show();
}

void infin(int red, int green, int blue) {

  if (ii == 0) {
    pixels.setPixelColor(6, pixels.Color(0, 0, 0));
    pixels.setPixelColor(0, pixels.Color(red, green, blue));
    pixels.show();
  }
  else if (ii == 1) {
    pixels.setPixelColor(1, pixels.Color(red, green, blue)); // Moderately bright green color.
    pixels.setPixelColor(0, pixels.Color(0, 0, 0));
    pixels.show(); // This sends the updated pixel color to the hardware.
  }
  else if (ii == 2) {
    pixels.setPixelColor(2, pixels.Color(red, green, blue)); // Moderately bright green color.
    pixels.setPixelColor(1, pixels.Color(0, 0, 0));
    pixels.show();
  }
  else if (ii == 3) {
    pixels.setPixelColor(3, pixels.Color(red, green, blue)); // Moderately bright green color.
    pixels.setPixelColor(2, pixels.Color(0, 0, 0));
    pixels.show();
  }
  else if (ii == 4) {
    pixels.setPixelColor(4, pixels.Color(red, green, blue)); // Moderately bright green color.
    pixels.setPixelColor(3, pixels.Color(0, 0, 0));
    pixels.show();
  }
  else if (ii == 5) {
    pixels.setPixelColor(5, pixels.Color(red, green, blue)); // Moderately bright green color.
    pixels.setPixelColor(4, pixels.Color(0, 0, 0));
    pixels.show();
  }
  else if (ii == 6) {
    pixels.setPixelColor(6, pixels.Color(red, green, blue)); // Moderately bright green color.
    pixels.setPixelColor(5, pixels.Color(0, 0, 0));
    pixels.show();
  }
  else if (ii == 7) {
    pixels.setPixelColor(12, pixels.Color(red, green, blue)); // Moderately bright green color.
    pixels.setPixelColor(6, pixels.Color(0, 0, 0));
    pixels.show();
  }
  else if (ii == 8) {
    pixels.setPixelColor(11, pixels.Color(red, green, blue)); // Moderately bright green color.
    pixels.setPixelColor(12, pixels.Color(0, 0, 0));
    pixels.show();
  }
  else if (ii == 9) {
    pixels.setPixelColor(10, pixels.Color(red, green, blue)); // Moderately bright green color.
    pixels.setPixelColor(11, pixels.Color(0, 0, 0));
    pixels.show();
  }
  else if (ii == 10) {
    pixels.setPixelColor(9, pixels.Color(red, green, blue)); // Moderately bright green color.
    pixels.setPixelColor(10, pixels.Color(0, 0, 0));
    pixels.show();
  }
  else if (ii == 11) {
    pixels.setPixelColor(8, pixels.Color(red, green, blue)); // Moderately bright green color.
    pixels.setPixelColor(9, pixels.Color(0, 0, 0));
    pixels.show();
  }
  else if (ii == 12) {
    pixels.setPixelColor(7, pixels.Color(red, green, blue)); // Moderately bright green color.
    pixels.setPixelColor(8, pixels.Color(0, 0, 0));
    pixels.show();
  }
  else if (ii == 13) {
    pixels.setPixelColor(6, pixels.Color(red, green, blue)); // Moderately bright green color.
    pixels.setPixelColor(7, pixels.Color(0, 0, 0));
    pixels.show();
  }


  if (ii > 12) {
    ii = 0;
  }
  else {
    ii = ii + 1;
  }

}

void pulse(int red, int green, int blue) {
  if (pi >= 200) {
    pi = 0;
  }

  //Brightness value counter
  if (pi <= 50) {
    pa = pa + 1;
  }
  if (pi > 50 && pa > 0) {
    pa = pa - 1;
  }

  float fA = float(pa);

  pixels.setPixelColor(6, pixels.Color(fA / 50 * red, fA / 50 * green, fA / 50 * blue));

  pixels.setPixelColor(5, pixels.Color(fA / 50 * red, fA / 50 * green, fA / 50 * blue));
  pixels.setPixelColor(0, pixels.Color(fA / 50 * red, fA / 50 * green, fA / 50 * blue));
  pixels.setPixelColor(7, pixels.Color(fA / 50 * red, fA / 50 * green, fA / 50 * blue));
  pixels.setPixelColor(12, pixels.Color(fA / 50 * red, fA / 50 * green, fA / 50 * blue));

  pixels.setPixelColor(1, pixels.Color(fA / 50 * red, fA / 50 * green, fA / 50 * blue));
  pixels.setPixelColor(4, pixels.Color(fA / 50 * red, fA / 50 * green, fA / 50 * blue));
  pixels.setPixelColor(8, pixels.Color(fA / 50 * red, fA / 50 * green, fA / 50 * blue));
  pixels.setPixelColor(11, pixels.Color(fA / 50 * red, fA / 50 * green, fA / 50 * blue));

  pixels.setPixelColor(2, pixels.Color(fA / 50 * red, fA / 50 * green, fA / 50 * blue));
  pixels.setPixelColor(3, pixels.Color(fA / 50 * red, fA / 50 * green, fA / 50 * blue));
  pixels.setPixelColor(9, pixels.Color(fA / 50 * red, fA / 50 * green, fA / 50 * blue));
  pixels.setPixelColor(10, pixels.Color(fA / 50 * red, fA / 50 * green, fA / 50 * blue));

  pixels.show();
  pi = pi + 1;
}


void burst(int red, int green, int blue) {
  if (bi >= 300) {
    bi = 0;
  }

  // a column
  if (bi <= 50) {
    ba = ba + 1;
  }
  if (bi > 50 && ba > 0) {
    ba = ba - 1;
  }

  // b column
  if (bi >= 25 && bi <= 75) {
    bb = bb + 1;
  }
  if (bi > 75 && bb > 0) {
    bb = bb - 1;
  }

  //c column
  if (bi >= 50 && bi <= 100) {
    bc = bc + 1;
  }
  if (bi > 100 && bc > 0) {
    bc = bc - 1;
  }

  //d column
  if (bi >= 75 && bi <= 125) {
    bd = bd + 1;
  }
  if (bi > 125 && bd > 0) {
    bd = bd - 1;
  }

  float fA = float(ba);
  float fB = float(bb);
  float fC = float(bc);
  float fD = float(bd);

  pixels.setPixelColor(6, pixels.Color(fA / 50 * red, fA / 50 * green, fA / 50 * blue));

  pixels.setPixelColor(5, pixels.Color(fB / 50 * red, fB / 50 * green, fB / 50 * blue));
  pixels.setPixelColor(0, pixels.Color(fB / 50 * red, fB / 50 * green, fB / 50 * blue));
  pixels.setPixelColor(7, pixels.Color(fB / 50 * red, fB / 50 * green, fB / 50 * blue));
  pixels.setPixelColor(12, pixels.Color(fB / 50 * red, fB / 50 * green, fB / 50 * blue));

  pixels.setPixelColor(1, pixels.Color(fC / 50 * red, fC / 50 * green, fC / 50 * blue));
  pixels.setPixelColor(4, pixels.Color(fC / 50 * red, fC / 50 * green, fC / 50 * blue));
  pixels.setPixelColor(8, pixels.Color(fC / 50 * red, fC / 50 * green, fC / 50 * blue));
  pixels.setPixelColor(11, pixels.Color(fC / 50 * red, fC / 50 * green, fC / 50 * blue));

  pixels.setPixelColor(2, pixels.Color(fD / 50 * red, fD / 50 * green, fD / 50 * blue));
  pixels.setPixelColor(3, pixels.Color(fD / 50 * red, fD / 50 * green, fD / 50 * blue));
  pixels.setPixelColor(9, pixels.Color(fD / 50 * red, fD / 50 * green, fD / 50 * blue));
  pixels.setPixelColor(10, pixels.Color(fD / 50 * red, fD / 50 * green, fD / 50 * blue));

  pixels.show();
  bi = bi + 1;
}

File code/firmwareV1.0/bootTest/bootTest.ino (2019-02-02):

/*
  Blink

  Turns an LED on for one second, then off for one second, repeatedly.

  Most Arduinos have an on-board LED you can control. On the UNO, MEGA and ZERO
  it is attached to digital pin 13, on MKR1000 on pin 6. LED_BUILTIN is set to
  the correct LED pin independent of which board is used.
  If you want to know what pin the on-board LED is connected to on your Arduino
  model, check the Technical Specs of your board at:
  https://www.arduino.cc/en/Main/Products

  modified 8 May 2014
  by Scott Fitzgerald
  modified 2 Sep 2016
  by Arturo Guadalupi
  modified 8 Sep 2016
  by Colby Newman

  This example code is in the public domain.

  http://www.arduino.cc/en/Tutorial/Blink
*/

// the setup function runs once when you press reset or power the board
void setup() {
  // initialize digital pin LED_BUILTIN as an output.
  pinMode(2, OUTPUT);
}

// the loop function runs over and over again forever
void loop() {
  digitalWrite(2, HIGH);   // turn the LED on (HIGH is the voltage level)
  delay(1000);                       // wait for a second
  digitalWrite(2 , LOW);    // turn the LED off by making the voltage LOW
  delay(1000);                       // wait for a second
}

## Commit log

2019-02-17 added programmer cad, updated glowtie cad, cleaned up directory structure
    [backPanel.stl, bumper.step, bumper.stl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]
2019-05-19 second to last firmware push
    [glowtie-2019-01-12-19-27-49.sch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]
2019-07-28 updated firmware and cad for v1.0
    [bumper.stl, diffusion.dxf, frame.stl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]
2023-07-29 updating pcb to v1.1 with better grounding, more widely used LDO pinout
    [glowtie.kicad_pcb, glowtie.kicad_sch]
2023-12-10 adds v1.1 and docs page
    [glowtie.kicad_pcb]
2026-01-11 pushing up from melange
    [glowtie-B_Cu.gbl, glowtie-B_Mask.gbs, glowtie-B_Silkscreen.gbo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]
